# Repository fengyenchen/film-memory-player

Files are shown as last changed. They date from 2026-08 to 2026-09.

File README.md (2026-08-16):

# Film Memory Player

以旋轉底片為互動概念的數位照片播放器。本儲存庫收錄兩種 ESP32 開發板版本；兩者共用同一份正式韌體，程式會依編譯目標自動套用對應的 GPIO。

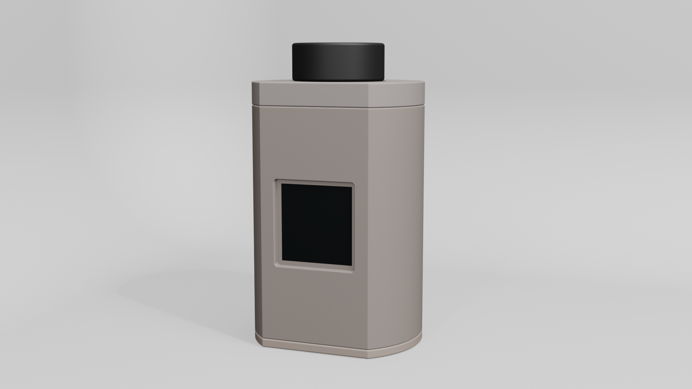
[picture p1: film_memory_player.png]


## 硬體版本

| 版本 | 開發板 | 專案文件 |
| --- | --- | --- |
| XIAO ESP32-C3 | Seeed Studio XIAO ESP32-C3 | [進入專案](xiao-esp32c3/README.md) |
| ESP32-S3 Super Mini | 具 B+ / B- 電池焊盤的 ESP32-S3 Super Mini | [進入專案](esp32-s3-super-mini/README.md) |

正式程式位於 [`firmware/FilmMemoryPlayer/`](firmware/FilmMemoryPlayer/)，只需在 Arduino IDE 選擇正確開發板。各版本資料夾保留接線說明、材料清單與元件測試程式。外殼的 STL 檔可到 [`3d-print-parts/`](3d-print-parts/) 取得。

## 資料夾導覽

```text
.
├─ 3d-print-parts/          外殼的 3D 列印零件
├─ firmware/
│  └─ FilmMemoryPlayer/     S3 與 C3 共用的正式韌體
├─ xiao-esp32c3/            XIAO ESP32-C3 接線、測試與說明
└─ esp32-s3-super-mini/     ESP32-S3 Super Mini 接線、測試與說明
```

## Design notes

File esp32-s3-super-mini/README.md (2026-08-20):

# Film Memory Player

Film Memory Player 是一個以「旋轉底片」為互動概念的數位照片播放器。使用 ESP32-S3 Super Mini、128×128 SPI TFT 與 EC11 旋轉編碼器，完成一台能播放照片、切換自動播放並透過 Wi-Fi 管理相冊的小型裝置。USB-C 可同時供電、燒錄並透過板載充電電路替 LiPo 充電。

## 完成後可以做什麼

- 左右旋轉 EC11 切換上一張或下一張照片。
- 短按旋鈕開啟或停止自動播放。
- 長按約 1.2 秒開啟主選單或返回主選單。
- 主選單可選擇相片、時鐘、表情、Wi-Fi 管理與設定。
- 從手機或電腦一次選擇多張照片上傳。
- 網頁會將照片裁切並縮放成 128×128 JPEG。
- 相片列表提供縮圖、日期時間檔名與單張刪除。
- 可在設定頁調整 `25%`、`50%`、`75%` 或 `100%` 螢幕亮度。
- `SETTINGS` 顯示由 GPIO11 分壓量測的約略電量與電池電壓。
- 長按約 3.5 秒關閉背光並進入休眠；再按一下即可重新啟動。
- 最多儲存 50 張照片。

## 主要材料

- ESP32-S3 Super Mini（具 B+ / B- 電池焊盤版本）
- 128×128 SPI TFT 顯示器
- EC11 旋轉編碼器（含按壓功能）
- 具保護板的單節 3.7V LiPo
- USB-C 傳輸線
- 杜邦線或焊接線材
- 3D 列印外殼

完整品項請看 [材料清單](docs/BOM.md)，接線方式請看 [接線指南](docs/WIRING.md)。

## 資料夾導覽

```text
film_memory_player/
├─ firmware/FilmMemoryPlayer/        S3 與 C3 共用的正式韌體
└─ esp32-s3-super-mini/
   ├─ docs/
   │  ├─ BOM.md                      材料清單
   │  └─ WIRING.md                   接線指南
   ├─ firmware/
   │  ├─ test_button/                EC11 按壓測試
   │  ├─ test_screen/                TFT 紅色畫面測試
   │  └─ test_wifi/                  Wi-Fi 熱點測試
```

外殼的 STL 檔可到專案最外層的 [`3d-print-parts/`](../3d-print-parts/) 取得。

## 建議流程

### 1. 安裝 Arduino IDE 與開發板

在 Arduino IDE 中安裝 ESP32 開發板支援，並選擇：

- 開發板：`ESP32S3 Dev Module`
- USB CDC On Boot：`Enabled`
- USB Mode：`Hardware CDC and JTAG`
- Flash Size：`4MB`
- Partition Scheme：`Custom`
- Serial Monitor：`115200 baud`

### 2. 安裝正式韌體需要的函式庫

從 Arduino IDE Library Manager 安裝：

- `Adafruit GFX Library`
- `Adafruit ST7735 and ST7789 Library`
- `TJpg_Decoder`

`LittleFS`、`WiFi` 與 `WebServer` 由 ESP32 開發板套件提供。

### 3. 依序測試元件

建議先完成單項測試，再燒錄正式韌體：

1. [按鈕測試](firmware/test_button/README.md)：確認 GPIO8 能讀到按下與放開。
2. [螢幕測試](firmware/test_screen/README.md)：確認 128×128 顯示區域能完整顯示紅色。
3. [Wi-Fi 測試](firmware/test_wifi/README.md)：確認手機能找到並連上測試熱點。

每個測試資料夾都有獨立的 `.ino` 與操作說明。測試程式會取代板上原本的程式，完成測試後再上傳正式韌體即可。

### 4. 燒錄正式韌體

1. 開啟專案最外層的 [`firmware/FilmMemoryPlayer/FilmMemoryPlayer.ino`](../firmware/FilmMemoryPlayer/FilmMemoryPlayer.ino)。
2. 確認同一個資料夾內保留 `partitions.csv`。
3. 編譯並上傳。
4. 上傳完成後按一下開發板的 RESET。

如果 Arduino IDE 無法連線：

1. 按住開發板的 BOOT。
2. 按一下 RESET。
3. 放開 BOOT。
4. 再次執行上傳。

## 接線摘要

| 功能 | ESP32-S3 Super Mini GPIO |
| --- | ---: |
| TFT 背光 BL | 1 |
| TFT RST | 2 |
| TFT DC | 4 |
| TFT CS | 5 |
| EC11 CLK | 6 |
| EC11 DT | 7 |
| TFT SCL | 9 |
| TFT SDA | 10 |
| EC11 SW | 8 |
| 電池電壓 ADC | 11（經兩顆 100kΩ 電阻分壓） |

TFT VCC 接 `3V3`，TFT 與 EC11 的 GND 都接到開發板 GND。詳細接法以 [WIRING.md](docs/WIRING.md) 為準。

## 操作方式

| 操作 | 功能 |
| --- | --- |
| 向右旋轉 | 下一張照片 |
| 向左旋轉 | 上一張照片 |
| 短按 | 開啟／停止自動播放 |
| 長按約 1.2 秒後放開 | 開啟主選單／返回主選單 |
| 持續按住約 3.5 秒 | 關閉背光並進入休眠 |
| 休眠後按一下 | 重新啟動 |

## 上傳與管理照片

1. 長按旋鈕約 1.2 秒開啟主選單。
2. 旋轉至 `WI-FI`，短按進入；看到螢幕顯示 `WIFI READY`。
3. 手機或電腦連接 Wi-Fi：
   - 預設名稱：`FilmMemory-Setup`
   - 預設密碼：`film2026`
4. 瀏覽器開啟 `http://192.168.4.1`。
5. 選擇照片並按下「裁切並上傳」。
6. 在下方列表查看縮圖，或刪除指定照片。
7. 在 Wi-Fi 模式短按旋鈕即可關閉 Wi-Fi 並回到主選單。

## 模式說明

- `PHOTO`：旋轉切換照片，短按開啟或暫停幻燈片。
- `CLOCK`：顯示日期與時間；進入 Wi-Fi 管理網頁時會從手機或電腦同步時間，完全斷電後需再次同步。
- `WI-FI`：啟動照片管理熱點與網頁。
- `SETTINGS`：旋轉調整幻燈片間隔、自動休眠時間或螢幕亮度，短按切換設定項目；底部顯示約略電量與電壓。

手機顯示「此網路沒有網際網路」是正常的，請保持連線並直接開啟管理網址。

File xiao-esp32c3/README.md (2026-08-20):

# Film Memory Player

Film Memory Player 是一個以「旋轉底片」為互動概念的數位照片播放器。使用 Seeed Studio XIAO ESP32-C3、128×128 SPI TFT 與 EC11 旋轉編碼器，完成一台能播放照片、切換自動播放並透過 Wi-Fi 管理相冊的小型裝置。USB-C 可同時供電、燒錄與替板載 LiPo 充電

## 完成後可以做什麼

- 左右旋轉 EC11 切換上一張或下一張照片。
- 短按旋鈕開啟或停止自動播放。
- 長按約 1.2 秒開啟主選單或返回主選單。
- 主選單可選擇相片、時鐘、表情、Wi-Fi 管理與設定。
- 從手機或電腦一次選擇多張照片上傳。
- 網頁會將照片裁切並縮放成 128×128 JPEG。
- 相片列表提供縮圖、日期時間檔名與單張刪除。
- 可在設定頁調整 `25%`、`50%`、`75%` 或 `100%` 螢幕亮度。
- 可在設定頁查看由 D1/A1（GPIO3）量測的約略電量與電壓。
- 長按約 3.5 秒關閉背光並進入休眠；再按一下即可重新啟動。
- 最多儲存 50 張照片。

## 主要材料

- Seeed Studio XIAO ESP32-C3
- 128×128 SPI TFT 顯示器
- EC11 旋轉編碼器（含按壓功能）
- 具保護板的單節 3.7V LiPo
- 100kΩ、1% 電阻兩顆（電池電壓分壓）
- USB-C 傳輸線
- 杜邦線或焊接線材
- 3D 列印外殼

完整品項請看 [材料清單](docs/BOM.md)，接線方式請看 [接線指南](docs/WIRING.md)。

## 資料夾導覽

```text
film_memory_player/
├─ firmware/FilmMemoryPlayer/        S3 與 C3 共用的正式韌體
└─ xiao-esp32c3/
   ├─ docs/
   │  ├─ BOM.md                      材料清單
   │  └─ WIRING.md                   接線指南
   ├─ firmware/
   │  ├─ test_button/                EC11 按壓測試
   │  ├─ test_screen/                TFT 紅色畫面測試
   │  └─ test_wifi/                  Wi-Fi 熱點測試
```

外殼的 STL 檔可到專案最外層的 [`3d-print-parts/`](../3d-print-parts/) 取得。

## 建議流程

### 1. 安裝 Arduino IDE 與開發板

在 Arduino IDE 中安裝 ESP32 開發板支援，並選擇：

- 開發板：`ESP32C3 Dev Module`
- USB CDC On Boot：`Enabled`
- Flash Size：`4MB`
- Partition Scheme：`Custom`
- Serial Monitor：`115200 baud`

### 2. 安裝正式韌體需要的函式庫

從 Arduino IDE Library Manager 安裝：

- `Adafruit GFX Library`
- `Adafruit ST7735 and ST7789 Library`
- `TJpg_Decoder`

`LittleFS`、`WiFi` 與 `WebServer` 由 ESP32 開發板套件提供。

### 3. 依序測試元件

建議先完成單項測試，再燒錄正式韌體：

1. [按鈕測試](firmware/test_button/README.md)：確認 GPIO21 能讀到按下與放開。
2. [螢幕測試](firmware/test_screen/README.md)：確認 128×128 顯示區域能完整顯示紅色。
3. [Wi-Fi 測試](firmware/test_wifi/README.md)：確認手機能找到並連上測試熱點。

每個測試資料夾都有獨立的 `.ino` 與操作說明。測試程式會取代板上原本的程式，完成測試後再上傳正式韌體即可。

### 4. 燒錄正式韌體

1. 開啟專案最外層的 [`firmware/FilmMemoryPlayer/FilmMemoryPlayer.ino`](../firmware/FilmMemoryPlayer/FilmMemoryPlayer.ino)。
2. 確認同一個資料夾內保留 `partitions.csv`。
3. 編譯並上傳。
4. 上傳完成後按一下 XIAO Reset。

如果 Arduino IDE 無法連線：

1. 按住 XIAO 的 BOOT。
2. 按一下 RESET。
3. 放開 BOOT。
4. 再次執行上傳。

## 接線摘要

| 功能 | XIAO GPIO |
| --- | ---: |
| TFT 背光 BL | 2 |
| TFT RST | 20（D7） |
| TFT DC | 4 |
| TFT CS | 5 |
| EC11 CLK | 6 |
| EC11 DT | 7 |
| TFT SCL | 8 |
| TFT SDA | 10 |
| EC11 SW | 21 |
| 電池 ADC | 3（D1 / A1，須經兩顆 100kΩ 分壓） |

TFT VCC 接 `3V3`，TFT、EC11 與電池分壓電路的 GND 都接到 XIAO GND。不可將 BAT+ 直接接 GPIO3；詳細接法以 [WIRING.md](docs/WIRING.md) 為準。

## 操作方式

| 操作 | 功能 |
| --- | --- |
| 向右旋轉 | 下一張照片 |
| 向左旋轉 | 上一張照片 |
| 短按 | 開啟／停止自動播放 |
| 長按約 1.2 秒後放開 | 開啟主選單／返回主選單 |
| 持續按住約 3.5 秒 | 關閉背光並進入休眠 |
| 休眠後按一下 | 重新啟動 |

## 上傳與管理照片

1. 長按旋鈕約 1.2 秒後放開，進入主選單。
2. 旋轉到 `WI-FI`，短按進入並等待畫面顯示 `WIFI READY`。
3. 手機或電腦連接 Wi-Fi：
   - 預設名稱：`FilmMemory-Setup`
   - 預設密碼：`film2026`
4. 瀏覽器開啟 `http://192.168.4.1`。
5. 選擇照片並按下「裁切並上傳」。
6. 在下方列表查看縮圖，或刪除指定照片。
7. 在 Wi-Fi 模式短按旋鈕即可關閉 Wi-Fi 並回到主選單。

手機顯示「此網路沒有網際網路」是正常的，請保持連線並直接開啟管理網址。

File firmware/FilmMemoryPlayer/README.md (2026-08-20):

# Film Memory Player 共用韌體

這是共用的正式韌體。程式會依 Arduino IDE 選擇的編譯目標，自動在 `Config.h` 套用對應 GPIO。使用 128×128 SPI TFT、EC11 旋轉編碼器與板載 LittleFS，提供照片播放、時鐘、表情、Wi-Fi 相簿管理、設定與休眠功能。

## 功能

- 從 LittleFS 播放最多 50 張照片。
- 手動切換照片或啟用自動播放。
- 顯示日期、星期與時間。
- 旋轉選擇 10 種黑底白線表情。
- 透過手機瀏覽器上傳、預覽、刪除或清空照片。
- 調整幻燈片間隔、自動休眠時間與螢幕亮度。
- 可在設定頁顯示約略電量與電壓；S3 使用 GPIO11，XIAO C3 使用 D1/A1（GPIO3），兩者都需外接兩顆 100kΩ 分壓電阻。
- 長按旋鈕進入低功耗休眠，再按一下喚醒。
- 自動保存設定與最後選擇的表情。

## Arduino IDE 準備

### 1. 安裝開發板套件

在 Arduino IDE 的 Boards Manager 安裝 Espressif 的 `esp32` 套件，再依開發板設定：

| 選項 | ESP32-S3 Super Mini | XIAO ESP32-C3 |
| --- | --- | --- |
| Board | `ESP32S3 Dev Module` | `ESP32C3 Dev Module` |
| USB CDC On Boot | `Enabled` | `Enabled` |
| Partition Scheme | `Custom` | `Custom` |
| Serial Monitor | `115200 baud` | `115200 baud` |

### 2. 安裝函式庫

從 Library Manager 安裝：

- `Adafruit GFX Library`
- `Adafruit ST7735 and ST7789 Library`
- `TJpg_Decoder`

`LittleFS`、`WiFi`、`WebServer`、`Preferences` 與 `SPI` 由 ESP32 開發板套件提供。

## 編譯與燒錄

1. 保持這個資料夾名稱為 `FilmMemoryPlayer`。
2. 確認所有 `.cpp`、`.h`、`.ino` 與 `partitions.csv` 都在同一個資料夾。
3. 使用 Arduino IDE 開啟 [FilmMemoryPlayer.ino](FilmMemoryPlayer.ino)。
4. 依實際硬體選擇開發版，程式會自動套用對應接腳。
5. 選擇正確的 USB 連接埠。
6. 按下 Verify 確認可以編譯。
7. 按下 Upload 燒錄。
8. 上傳完成後按一下開發板的 RESET。

若無法進入燒錄模式：

1. 按住開發板的 BOOT。
2. 按一下 RESET。
3. 放開 BOOT。
4. 再次執行 Upload。

`partitions.csv` 會建立約 1.94 MiB 的照片儲存空間。請勿刪除或改名；更換 Partition Scheme、格式化或重新分割 Flash 可能清除已上傳的照片。

## 首次使用

1. 開機後裝置進入 `PHOTO` 模式。
2. 如果尚未上傳照片，畫面會顯示 `NO PHOTOS`。
3. 長按旋鈕約 1.2 秒後放開，進入主選單。
4. 旋轉到 `WI-FI`，短按進入。
5. 用手機連接：
   - Wi-Fi：`FilmMemory-Setup`
   - 密碼：`film2026`
6. 瀏覽器開啟 [http://192.168.4.1](http://192.168.4.1)。
7. 選取照片、裁切並上傳。
8. 在 Wi-Fi 模式短按旋鈕，關閉熱點並回到主選單。
9. 進入 `PHOTO` 開始播放。

網頁會將圖片裁切並縮放為 128×128 JPEG。管理頁開啟時也會用手機／電腦時間同步裝置時鐘。

## 操作方式

### 共通操作

| 操作 | 功能 |
| --- | --- |
| 長按約 1.2 秒後放開 | 從目前模式進入主選單 |
| 在主選單旋轉 | 選擇模式 |
| 在主選單短按 | 進入選取的模式 |
| 持續按住約 3.5 秒 | 關閉背光並進入休眠 |
| 休眠時按一下並放開 | 喚醒並重新啟動 |

### 模式

| 模式 | 旋轉 | 短按 | 說明 |
| --- | --- | --- | --- |
| `PHOTO` | 上一張／下一張 | 開啟或停止幻燈片 | 播放 LittleFS 相簿 |
| `CLOCK` | 無 | 無 | 顯示時間、日期與星期 |
| `EMOTES` | 切換表情 | 無 | 顯示 10 種靜態線條表情 |
| `WI-FI` | 無 | 關閉 Wi-Fi 並回主選單 | 啟動照片管理頁 |
| `SETTINGS` | 修改目前選項 | 切換下一個選項 | 設定幻燈片、自動休眠與亮度，並顯示約略電量 |

幻燈片可選 `2`、`3.5`、`5`、`10` 秒；自動休眠可選 `OFF`、`1`、`3`、`5` 分鐘；螢幕亮度可選 `25%`、`50%`、`75%`、`100%`。設定會自動保存，重新開機後仍會套用。

如果剛旋轉完照片，程式會短暫忽略按鍵，以免轉動旋鈕時誤觸自動播放。

## Wi-Fi 相簿管理

管理頁提供：

- 多張照片依序裁切與上傳。
- 顯示剩餘儲存空間。
- 照片縮圖與檔案資訊。
- 單張刪除或清空全部照片。
- 裝置時間同步。

Wi-Fi 模式是本機 SoftAP，不需要網際網路。手機若提示「此網路無網際網路」，仍可保持連線並開啟 `192.168.4.1`。

## 資料夾結構

```text
FilmMemoryPlayer/
├─ FilmMemoryPlayer.ino   # setup()、loop() 與初始化流程
├─ Config.h               # 自動選擇 S3/C3 GPIO，以及共用尺寸與常數
├─ BatteryMonitor.h/.cpp  # S3/C3 電池電壓與百分比估算
├─ AppState.h/.cpp        # 共用狀態、TFT、WebServer、Preferences
├─ DisplayUtils.h/.cpp    # 背光、置中文字與訊息畫面
├─ PhotoMode.h/.cpp       # JPEG、照片掃描、顯示與切換
├─ ClockMode.h/.cpp       # 時鐘畫面
├─ EmoteMode.h/.cpp       # 線條表情繪製
├─ MenuMode.h/.cpp        # 主選單與模式切換
├─ SettingsMode.h/.cpp    # 設定畫面與保存
├─ WifiManager.h/.cpp     # Wi-Fi、上傳、刪除與時間同步
├─ WebPage.h/.cpp         # 內嵌管理網頁
├─ Encoder.h/.cpp         # EC11 旋轉、短按與長按
├─ PowerManager.h/.cpp    # 休眠與按鍵喚醒
├─ partitions.csv         # 4 MB Flash 自訂分割表
└─ README.md
```

Arduino IDE 會自動編譯同一個 sketch 資料夾內的所有 `.cpp` 檔。請勿只複製 `.ino`，否則會出現缺少標頭或未定義函式的錯誤。

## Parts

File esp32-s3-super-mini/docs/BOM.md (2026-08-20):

# 材料清單

| 分類 | 品項 | 規格 | 數量 | 備註 |
|---|---|---|---:|---|
| 電子 | 主控制器 | ESP32-S3 Super Mini（具 B+ / B- 焊盤版本） | 1 | 使用原生 USB-C 與板載 LiPo 充電電路 |
| 電子 | 顯示器 | 1.44 吋 128×128 ST7735S SPI TFT | 1 |  |
| 電子 | 旋轉編碼器 | EC11，6 mm D 軸、含按壓 | 1 |  | https://shopee.tw/EC11-360%E5%BA%A6%E9%80%A3%E7%BA%8C%E6%97%8B%E8%BD%89-%E7%B7%A8%E7%A2%BC%E5%99%A8%E6%A8%A1%E7%B5%84-%E6%95%B8%E4%BD%8D%E8%A8%8A%E8%99%9F-D%E5%AD%97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 |
| 電源 | 鋰電池 | 具保護板 503040 單節 3.7V LiPo | 1 | 正極接 B+、負極接 B-；不可接反 |
| 電子 | 分壓電阻 | 100kΩ、1%、1/4W 或更小 | 2 | 電池電量偵測，接到 GPIO11 |

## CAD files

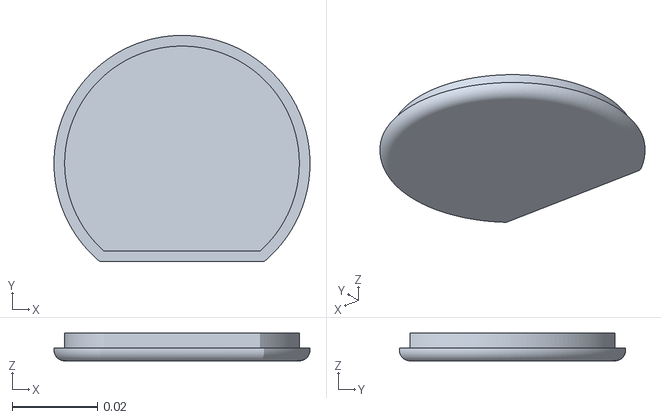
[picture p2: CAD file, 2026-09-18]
3d-print-parts/1.stl
0.06 x 0.053 x 0.0065

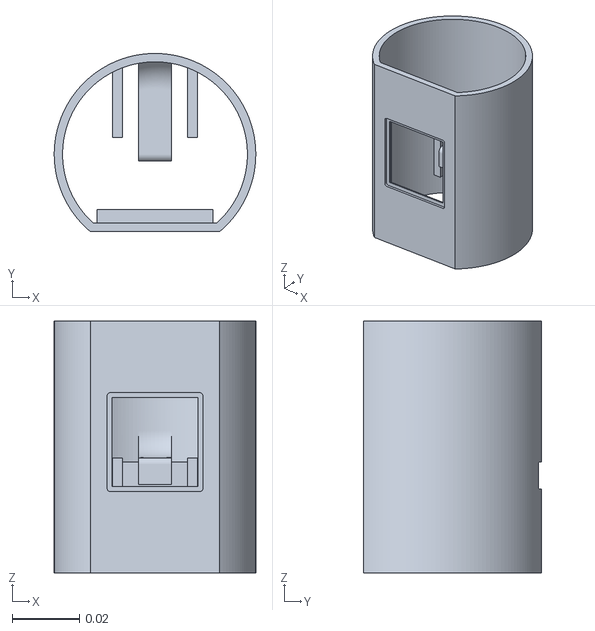
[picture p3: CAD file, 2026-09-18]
3d-print-parts/2.stl
0.06 x 0.053 x 0.075

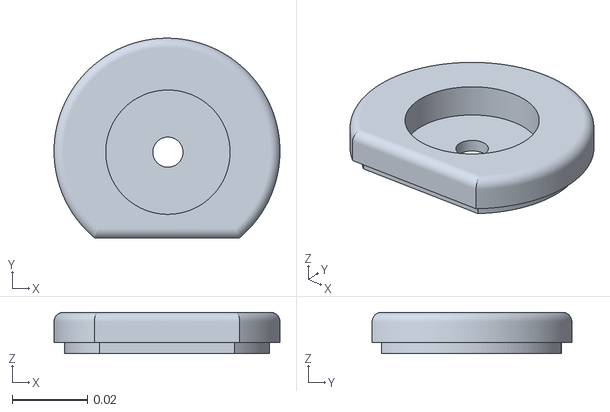
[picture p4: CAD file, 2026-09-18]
3d-print-parts/3.stl
0.06 x 0.053 x 0.011

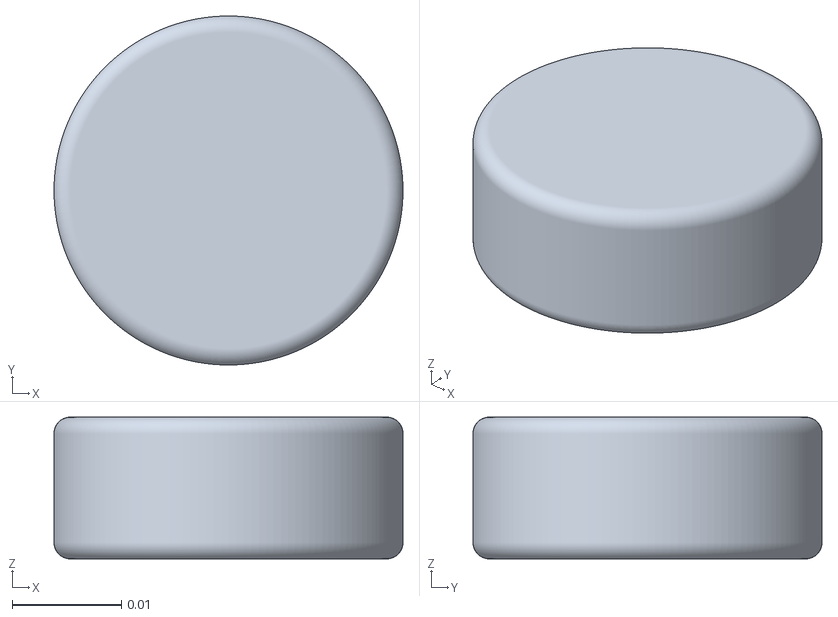
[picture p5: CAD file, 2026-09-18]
3d-print-parts/4.stl
0.032 x 0.032 x 0.013

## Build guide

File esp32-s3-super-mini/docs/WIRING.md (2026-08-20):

# 接線指南

## 主要控制板：ESP32-S3 Super Mini

本文件對應具有 `B+`、`B-` 電池焊盤的 ESP32-S3 Super Mini。所有模組必須共地：TFT、EC11 與分壓電路的 GND 都接到開發板 `GND`；TFT 與 EC11 使用開發板的 `3V3` 供電。

> **Wi-Fi 天線注意事項：**
> - 這塊板使用板載 PCB 天線，不需要另外安裝天線。
> - 天線端不要緊貼 LiPo、TFT 金屬背板或大量導線，也不要用金屬件包覆。

---

## 電池與充電

```text
LiPo 正極 → ESP32-S3 Super Mini 的 B+
LiPo 負極 → ESP32-S3 Super Mini 的 B-

USB-C 充電器 → ESP32-S3 Super Mini 原生 USB-C
```

USB-C 線直接插入開發板，另一端接一般 5V USB 充電器。只使用單節標稱 3.7V、充滿 4.2V 且具有保護板的 LiPo。

依此版本接腳圖標註，板載充電電路的預設充電電流約為 100mA。不同賣家的板子可能使用不同充電晶片，實際規格仍以商品頁為準。

> **電池安全：**
> - `B+`、`B-` 不可接反，也不可將 5V 接到 `B+`。
> - 不要同時使用外接 TP4056 與板載充電電路替同一顆電池充電。
> - 焊接前先拔除 USB-C，避免正負極或裸露接點短路。

---

## 電量偵測

使用兩顆 `100kΩ、1%` 電阻做 1:2 分壓。兩顆電阻的中間接點連到 GPIO11：

```text
B+ ── R1（100kΩ）──●── R2（100kΩ）── B-
                    │
                 GPIO11
```

- `B+` 焊盤同時焊接電池紅線與 R1 的一端。
- `B-` 焊盤同時焊接電池黑線與 R2 的一端。
- R1、R2 剩下的兩端焊在一起，形成中間接點，再從這裡接到 GPIO11。
- `B-` 與開發板 GND 共地；如果 B- 焊盤太擠，R2 下端也可以改接開發板的 GND 腳。

單節 LiPo 充滿時最高約 4.2V，經分壓後 GPIO11 約讀到 2.1V。不可將 `B+` 直接接到 GPIO11。`SETTINGS` 顯示的是依電壓估算的約略百分比；USB 充電或負載變化時，讀值可能浮動或偏高。

---

## 螢幕模組（ST7735S 128×128 SPI TFT）

這塊螢幕使用 SPI 通訊，背光由 ESP32-S3 Super Mini 的 GPIO1 直接控制。

| TFT 螢幕腳位標示 | 開發板腳位標示 | GPIO 編號 | 說明 |
| --- | --- | ---: | --- |
| **VCC / VDD** | `3V3` | - | 螢幕電源（3.3V） |
| **GND** | `GND` | - | 接地 |
| **SCL / SCK** | `GPIO9` | 9 | SPI 時脈線（Clock） |
| **SDA / MOSI** | `GPIO10` | 10 | SPI 資料線（Data） |
| **RES / RST** | `GPIO2` | 2 | 螢幕重置（Reset） |
| **DC / RS** | `GPIO4` | 4 | 資料／指令切換（Data/Command） |
| **CS / CE** | `GPIO5` | 5 | 晶片選擇（Chip Select） |
| **BLK / BL** | `GPIO1` | 1 | 螢幕背光直接控制 |

---

## 背光控制

```text
ESP32-S3 Super Mini GPIO1 → TFT BLK / BL
```

> **背光注意事項：**
> GPIO1 為 HIGH 時背光開啟，LOW 時背光關閉。進入休眠模式時，程式會將 GPIO1 鎖定為 LOW。

---

## 旋轉編碼器模組（EC11）

EC11 旋轉編碼器通常有 5 支腳：一側 3 支為旋轉訊號，另一側 2 支為按鈕訊號。

| EC11 腳位標示 | 開發板腳位標示 | GPIO 編號 | 說明 |
| --- | --- | ---: | --- |
| **GND / 共用端 C** | `GND` | - | 旋轉訊號的共用接地 |
| **+ / VCC** | `3V3` | - | 供電 |
| **CLK / A 相** | `GPIO6` | 6 | 旋轉觸發訊號 A |
| **DT / B 相** | `GPIO7` | 7 | 旋轉觸發訊號 B |
| **SW / 按壓開關** | `GPIO8` | 8 | 按鍵輸入與休眠喚醒訊號 |

> **編碼器注意事項：**
> 1. GPIO6、GPIO7、GPIO8 直接依照上表接線。
> 2. 如果向右轉卻變成上一張照片，將 CLK（GPIO6）與 DT（GPIO7）兩條線互換。

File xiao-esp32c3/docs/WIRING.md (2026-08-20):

# 接線指南

## 主要控制板：Seeed Studio XIAO ESP32-C3

本文件對應 Seeed Studio XIAO ESP32-C3。所有模組必須共地：TFT、EC11 與分壓電路的 GND 都接到開發板 `GND`；TFT 與 EC11 使用開發板的 `3V3` 供電。

> **Wi-Fi 天線注意事項：**
> - 確認 IPEX 天線接頭已確實垂直扣緊於 XIAO 的金色底座。
> - 天線貼片不要緊貼 LiPo、TFT 金屬背板或大量導線，也不要用金屬件包覆。
> - 天線盡量固定在遠離金屬與電源線的非金屬外殼內側。

---

## 電池與充電

```text
LiPo 正極 → XIAO 背面的 BAT+
LiPo 負極 → XIAO 背面的 BAT-

USB-C 充電器 → XIAO 原生 USB-C
```

USB-C 線直接插入開發板，另一端接一般 5V USB 充電器。只使用單節標稱 3.7V、充滿 4.2V 且具有保護板的 LiPo。

XIAO ESP32-C3 的官方充電電流約為 380mA，電池必須允許此充電電流。

> **電池安全：**
> - `BAT+`、`BAT-` 不可接反，也不可將 5V 接到 `BAT+`。
> - 不要同時使用外接 TP4056 與板載充電電路替同一顆電池充電。
> - 焊接前先拔除 USB-C，避免正負極或裸露接點短路。

---

## 電量偵測

使用兩顆 `100kΩ、1%` 電阻做 1:2 分壓。兩顆電阻的中間接點連到 D1 / A1（GPIO3）：

```text
BAT+ ── R1（100kΩ）──●── R2（100kΩ）── BAT-
                     │
               D1 / A1 / GPIO3
```

- `BAT+` 焊盤同時焊接電池紅線與 R1 的一端。
- `BAT-` 焊盤同時焊接電池黑線與 R2 的一端。
- R1、R2 剩下的兩端焊在一起，形成中間接點，再從這裡接到 D1 / A1（GPIO3）。
- `BAT-` 與開發板 GND 共地；如果 BAT- 焊盤太擠，R2 下端也可以改接開發板的 GND 腳。

單節 LiPo 充滿時最高約 4.2V，經分壓後 GPIO3 約讀到 2.1V。不可將 `BAT+` 直接接到 GPIO3。`SETTINGS` 顯示的是依電壓估算的約略百分比；USB 充電或負載變化時，讀值可能浮動或偏高。

---

## 螢幕模組（ST7735S 128×128 SPI TFT）

這塊螢幕使用 SPI 通訊，背光由 XIAO ESP32-C3 的 D0（GPIO2）直接控制。

| TFT 螢幕腳位標示 | 開發板腳位標示 | GPIO 編號 | 說明 |
| --- | --- | ---: | --- |
| **VCC / VDD** | `3V3` | - | 螢幕電源（3.3V） |
| **GND** | `GND` | - | 接地 |
| **SCL / SCK** | `D8` | 8 | SPI 時脈線（Clock） |
| **SDA / MOSI** | `D10` | 10 | SPI 資料線（Data） |
| **RES / RST** | `D7` | 20 | 螢幕重置（Reset） |
| **DC / RS** | `D2` | 4 | 資料／指令切換（Data/Command） |
| **CS / CE** | `D3` | 5 | 晶片選擇（Chip Select） |
| **BLK / BL** | `D0` | 2 | 螢幕背光直接控制 |

---

## 背光控制

```text
XIAO D0（GPIO2）→ TFT BLK / BL
```

> **背光注意事項：**
> D0（GPIO2）為 HIGH 時背光開啟，LOW 時背光關閉。進入休眠模式時，程式會將 GPIO2 鎖定為 LOW。

---

## 旋轉編碼器模組（EC11）

EC11 旋轉編碼器通常有 5 支腳：一側 3 支為旋轉訊號，另一側 2 支為按鈕訊號。

| EC11 腳位標示 | 開發板腳位標示 | GPIO 編號 | 說明 |
| --- | --- | ---: | --- |
| **GND / 共用端 C** | `GND` | - | 旋轉訊號的共用接地 |
| **+ / VCC** | `3V3` | - | 供電 |
| **CLK / A 相** | `D4` | 6 | 旋轉觸發訊號 A |
| **DT / B 相** | `D5` | 7 | 旋轉觸發訊號 B |
| **SW / 按壓開關** | `D6` | 21 | 按鍵輸入與休眠喚醒訊號 |

> **編碼器注意事項：**
> 1. D4、D5、D6 直接依照上表接線。
> 2. 如果向右轉卻變成上一張照片，將 CLK（D4）與 DT（D5）兩條線互換。

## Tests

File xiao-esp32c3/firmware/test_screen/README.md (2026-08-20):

# TFT 螢幕測試

這個測試會直接向 128×128 TFT 寫入純紅色畫面，用來確認螢幕供電、SPI 接線、重設腳位與顯示範圍是否正常。

## 接線

| TFT 腳位 | XIAO ESP32-C3 |
| --- | --- |
| VCC / VDD | 3V3 |
| GND | GND |
| BLK / BL | GPIO2 |
| RES / RST | GPIO20（D7） |
| DC / RS | GPIO4 |
| CS / CE | GPIO5 |
| SCL / SCK | GPIO8 |
| SDA / MOSI | GPIO10 |

## Arduino IDE 設定

- 開發板：`XIAO_ESP32C3`
- USB CDC On Boot：`Enabled`
- 上傳檔案：`test_screen.ino`
- 這個測試直接傳送顯示指令，不需要額外顯示函式庫。

## 測試步驟

1. 先拔除 USB-C，再依照接線表連接 TFT。
2. 再接上 USB-C，開啟並上傳 `test_screen.ino`。
3. 等待約 1 秒觀察螢幕。

## 成功判定

整個 128×128 顯示區域呈現均勻紅色，沒有白邊、位移、雜色或破碎區塊，即代表主要螢幕接線正常。

## 背光測試方式

程式會在初始化期間先關閉 GPIO2 背光，完成純紅色畫面寫入後再開啟，因此啟動時短暫黑屏是正常現象。

## 常見問題

- 完全不亮：先確認 GPIO2 背光控制與 3V3、GND。
- 全白：優先檢查 GPIO20、GPIO4、GPIO5、GPIO8、GPIO10。
- 有畫面但位置偏移：確認使用的是本專案測試過的 128×128 面板。
- 顏色不是紅色：可能是面板色彩順序不同，可再確認初始化設定。

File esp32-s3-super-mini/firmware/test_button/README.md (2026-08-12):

# 按鈕測試

這個測試用來確認 EC11 旋鈕的按壓開關是否能被 ESP32-S3 Super Mini 正確讀取。

## 接線

| EC11 按鈕腳位 | ESP32-S3 Super Mini |
| --- | --- |
| SW | GPIO8 |
| 按鈕另一腳 | GND |

## Arduino IDE 設定

- 開發板：`ESP32S3 Dev Module`
- USB CDC On Boot：`Enabled`
- Partition Scheme：`Custom`
- Serial Monitor：`115200 baud`
- 上傳檔案：`test_button.ino`

## 測試步驟

1. 完成接線後，以 USB-C 將 ESP32-S3 Super Mini 連接電腦。
2. 開啟 `test_button.ino` 並上傳。
3. 開啟 Arduino IDE 的 Serial Monitor。
4. 不按旋鈕時，應持續看到 `未按下 (HIGH)`。
5. 按住旋鈕時，應看到 LOW 訊息。
6. 放開旋鈕後，應恢復顯示 HIGH。

## 成功判定

按下與放開時，Serial Monitor 能在 LOW 與 HIGH 之間切換，表示按壓開關、GPIO8 與 GND 接線正常。

## 常見問題

- 一直顯示 HIGH：檢查 SW 是否接到 GPIO8，以及按鈕另一腳是否接到 GND。
- 一直顯示 LOW：檢查 SW 線與 GND 是否短接，或旋鈕是否卡在按下狀態。
- Serial Monitor 沒有文字：確認傳輸速率為 115200、USB CDC On Boot 已啟用，並按一下 RESET。

> 這個程式只測試旋鈕按壓，不測試左右旋轉。

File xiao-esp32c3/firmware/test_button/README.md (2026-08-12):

# 按鈕測試

這個測試用來確認 EC11 旋鈕的按壓開關是否能被 XIAO ESP32-C3 正確讀取。

## 接線

| EC11 按鈕腳位 | XIAO ESP32-C3 |
| --- | --- |
| SW | GPIO21 |
| 按鈕另一腳 | GND |

## Arduino IDE 設定

- 開發板：`XIAO_ESP32C3`
- USB CDC On Boot：`Enabled`
- Partition Scheme：`Custom`
- Serial Monitor：`115200 baud`
- 上傳檔案：`test_button.ino`

## 測試步驟

1. 完成接線後，以 USB-C 將 XIAO 連接電腦。
2. 開啟 `test_button.ino` 並上傳。
3. 開啟 Arduino IDE 的 Serial Monitor。
4. 不按旋鈕時，應持續看到 `未按下 (HIGH)`。
5. 按住旋鈕時，應看到 LOW 訊息。
6. 放開旋鈕後，應恢復顯示 HIGH。

## 成功判定

按下與放開時，Serial Monitor 能在 LOW 與 HIGH 之間切換，表示按壓開關、GPIO21 與 GND 接線正常。

## 常見問題

- 一直顯示 HIGH：檢查 SW 是否接到 GPIO21，以及按鈕另一腳是否接到 GND。
- 一直顯示 LOW：檢查 SW 線與 GND 是否短接，或旋鈕是否卡在按下狀態。
- Serial Monitor 沒有文字：確認傳輸速率為 115200，並按一下 XIAO Reset。

> 這個程式只測試旋鈕按壓，不測試左右旋轉。

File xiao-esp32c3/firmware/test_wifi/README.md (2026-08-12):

# Wi-Fi 熱點測試

這個測試用來確認 XIAO ESP32-C3 能否建立 Wi-Fi SoftAP 熱點，以及手機能否找到並連線。

## 測試前準備

- 將外接 Wi-Fi 天線垂直扣緊在 XIAO 的天線接座。
- 天線不要貼在電池、TFT 金屬背板或大量導線旁邊。
- 這個測試不需要連接 TFT 或 EC11。

## Arduino IDE 設定

- 開發板：`XIAO_ESP32C3`
- USB CDC On Boot：`Enabled`
- Serial Monitor：`115200 baud`
- 上傳檔案：`test_wifi.ino`

## 測試步驟

1. 使用 USB-C 將 XIAO 連接電腦。
2. 上傳 `test_wifi.ino`。
3. 開啟 Serial Monitor。
4. 用手機搜尋 Wi-Fi 網路 `XIAO-Test-AP`。
5. 這是測試用的開放網路，不需要密碼。
6. 連線後，Serial Monitor 應顯示熱點 IP，通常是 `192.168.4.1`。

## 成功判定

- Serial Monitor 顯示 `熱點發射成功`。
- 手機可以找到並連上 `XIAO-Test-AP`。
- 手機提示「沒有網際網路」是正常現象，這個熱點只用於裝置本機通訊。

## 常見問題

- 手機找不到熱點：確認天線接頭已扣緊，然後按一下 XIAO Reset。
- Serial Monitor 沒有文字：確認傳輸速率為 115200。
- 顯示熱點發射失敗：重新插拔 USB-C，再次上傳測試程式。
- 手機自動切回行動網路：暫時關閉手機的自動切換網路功能，再重新連線。

> 正式韌體使用的熱點名稱與密碼和此測試程式不同；這個開放熱點只用於確認 Wi-Fi 硬體功能。

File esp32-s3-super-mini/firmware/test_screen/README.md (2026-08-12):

# TFT 螢幕測試

這個測試會直接向 128×128 TFT 寫入純紅色畫面，用來確認螢幕供電、SPI 接線、重設腳位與顯示範圍是否正常。

## 接線

| TFT 腳位 | ESP32-S3 Super Mini |
| --- | --- |
| VCC / VDD | 3V3 |
| GND | GND |
| BLK / BL | GPIO1 |
| RES / RST | GPIO2 |
| DC / RS | GPIO4 |
| CS / CE | GPIO5 |
| SCL / SCK | GPIO9 |
| SDA / MOSI | GPIO10 |

## Arduino IDE 設定

- 開發板：`ESP32S3 Dev Module`
- USB CDC On Boot：`Enabled`
- 上傳檔案：`test_screen.ino`
- 這個測試直接傳送顯示指令，不需要額外顯示函式庫。

## 測試步驟

1. 先拔除 USB-C，再依照接線表連接 TFT。
2. 再接上 USB-C，開啟並上傳 `test_screen.ino`。
3. 等待約 1 秒觀察螢幕。

## 成功判定

整個 128×128 顯示區域呈現均勻紅色，沒有白邊、位移、雜色或破碎區塊，即代表主要螢幕接線正常。

## 背光測試方式

程式會在初始化期間先關閉 GPIO1 背光，完成純紅色畫面寫入後再開啟，因此啟動時短暫黑屏是正常現象。

## 常見問題

- 完全不亮：先確認 GPIO1 背光控制與 3V3、GND。
- 全白：優先檢查 GPIO2、GPIO4、GPIO5、GPIO9、GPIO10。
- 有畫面但位置偏移：確認使用的是本專案測試過的 128×128 面板。
- 顏色不是紅色：可能是面板色彩順序不同，可再確認初始化設定。

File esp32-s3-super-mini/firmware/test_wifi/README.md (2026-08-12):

# Wi-Fi 熱點測試

這個測試用來確認 ESP32-S3 Super Mini 能否建立 Wi-Fi SoftAP 熱點，以及手機能否找到並連線。

## 測試前準備

- 板載 PCB 天線端不要緊貼電池、TFT 金屬背板或大量導線。
- 這個測試不需要連接 TFT 或 EC11。

## Arduino IDE 設定

- 開發板：`ESP32S3 Dev Module`
- USB CDC On Boot：`Enabled`
- Serial Monitor：`115200 baud`
- 上傳檔案：`test_wifi.ino`

## 測試步驟

1. 使用 USB-C 將 ESP32-S3 Super Mini 連接電腦。
2. 上傳 `test_wifi.ino`。
3. 開啟 Serial Monitor。
4. 用手機搜尋 Wi-Fi 網路 `S3-SuperMini-Test`。
5. 這是測試用的開放網路，不需要密碼。
6. 連線後，Serial Monitor 應顯示熱點 IP，通常是 `192.168.4.1`。

## 成功判定

- Serial Monitor 顯示 `熱點發射成功`。
- 手機可以找到並連上 `S3-SuperMini-Test`。
- 手機提示「沒有網際網路」是正常現象，這個熱點只用於裝置本機通訊。

## 常見問題

- 手機找不到熱點：讓板載天線遠離金屬遮蔽物，然後按一下 RESET。
- Serial Monitor 沒有文字：確認傳輸速率為 115200。
- 顯示熱點發射失敗：重新插拔 USB-C，再次上傳測試程式。
- 手機自動切回行動網路：暫時關閉手機的自動切換網路功能，再重新連線。

> 正式韌體使用的熱點名稱與密碼和此測試程式不同；這個開放熱點只用於確認 Wi-Fi 硬體功能。

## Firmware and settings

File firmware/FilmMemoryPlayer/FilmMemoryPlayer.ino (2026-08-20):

/*
 * Film Memory Player
 *
 * The sketch entry point coordinates initialization and the main loop.
 * Feature implementations live in the adjacent .cpp/.h modules.
 */

#include <Arduino.h>
#include <LittleFS.h>
#include <SPI.h>
#include <TJpg_Decoder.h>
#include <driver/gpio.h>
#include <sys/time.h>
#include <time.h>

#include "AppState.h"
#include "BatteryMonitor.h"
#include "ClockMode.h"
#include "Config.h"
#include "DisplayUtils.h"
#include "Encoder.h"
#include "PhotoMode.h"
#include "PowerManager.h"

void setup() {
  Serial.begin(115200);
  delay(500);

  // 台灣時區；網頁會把手機／電腦的 Unix 時間同步給裝置。
  setenv("TZ", "CST-8", 1);
  tzset();
  preferences.begin("film-memory", false);
  slideIntervalIndex = preferences.getUChar("slide", 1);
  autoSleepIndex = preferences.getUChar("sleep", 0);
  brightnessIndex = preferences.getUChar("bright", BRIGHTNESS_OPTION_COUNT - 1);
  currentExpression = preferences.getUChar("emote", 0);
  if (slideIntervalIndex >= OPTION_COUNT) slideIntervalIndex = 1;
  if (autoSleepIndex >= OPTION_COUNT) autoSleepIndex = 0;
  if (brightnessIndex >= BRIGHTNESS_OPTION_COUNT) {
    brightnessIndex = BRIGHTNESS_OPTION_COUNT - 1;
  }
  if (currentExpression >= EXPRESSION_COUNT) currentExpression = 0;

  // 若前一次休眠鎖住背光腳，開機時先解除，再由程式正常控制。
  gpio_hold_dis(static_cast<gpio_num_t>(PIN_TFT_BL));
  pinMode(PIN_TFT_BL, OUTPUT);
  setBacklight(false); // 初始化完成前先關背光，避免看到白屏／雜訊

  pinMode(PIN_ENCODER_A, INPUT_PULLUP);
  pinMode(PIN_ENCODER_B, INPUT_PULLUP);
  pinMode(PIN_ENCODER_SW, INPUT_PULLUP);
  initBatteryMonitor();

  // 使用目前開發板的硬體 SPI，完整 128x128 畫面約十多毫秒送完。
  SPI.begin(PIN_TFT_SCK, -1, PIN_TFT_MOSI, PIN_TFT_CS);
  tft.init(DISPLAY_W, DISPLAY_H);
  tft.setSPISpeed(TFT_SPI_HZ);
  // 這塊 128x128 ST7735S 的可視記憶體從 (0,0) 開始。
  // 覆寫 Adafruit 預設的置中位移，確保繪圖座標對齊 (0,0) 至 (127,127)。
  tft.use128x128ZeroOffset();
  tft.fillScreen(ST77XX_BLACK);
  tft.invertDisplay(false);
  tft.sendCommand(0x36, (const uint8_t[]){0x08}, 1); // BGR 色彩修正
  setBacklight(true);

  TJpgDec.setJpgScale(1);
  TJpgDec.setSwapBytes(false);
  TJpgDec.setCallback(tftJpegOutput);

  encoderPrevious = (digitalRead(PIN_ENCODER_A) << 1) | digitalRead(PIN_ENCODER_B);
  buttonLastReading = buttonStable = digitalRead(PIN_ENCODER_SW);
  if (buttonStable == LOW) buttonPressedAt = millis();

  fileSystemReady = LittleFS.begin(true);
  if (!fileSystemReady) {
    showMessage("FS ERROR", "Formatting...");
    LittleFS.format();
    LittleFS.begin(true);
  }
  LittleFS.mkdir("/photos");
  scanPhotos();

  appMode = AppMode::PHOTO;
  lastUserActionAt = millis();
  drawPhoto();
}

void loop() {
  pollButton();

  if (setupMode) {
    server.handleClient();
    delay(2);
    return;
  }

  pollEncoder();
  const uint32_t now = millis();

  if (expressionSelectionDirty && now - expressionSelectionChangedAt >= 750) {
    preferences.putUChar("emote", currentExpression);
    expressionSelectionDirty = false;
  }

  if (appMode == AppMode::CLOCK && now - lastClockDrawAt >= 1000) {
    drawClock();
  }

  if (appMode == AppMode::PHOTO && autoplay && photoCount > 1 &&
      now - lastSlideAt >= SLIDE_INTERVALS_MS[slideIntervalIndex]) {
    currentPhoto = (currentPhoto + 1) % photoCount;
    lastSlideAt = now;
    drawPhoto();
  }

  const uint16_t sleepMinutes = AUTO_SLEEP_MINUTES[autoSleepIndex];
  if (sleepMinutes > 0 && now - lastUserActionAt >= uint32_t(sleepMinutes) * 60000UL) {
    enterSleep();
  }
  delay(1);
}

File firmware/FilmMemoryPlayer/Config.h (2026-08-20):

#pragma once

#include <Arduino.h>

#if defined(CONFIG_IDF_TARGET_ESP32S3)

constexpr char BOARD_NAME[] = "ESP32-S3 Super Mini";
constexpr int PIN_TFT_BL = 1;
constexpr int PIN_TFT_RST = 2;
constexpr int PIN_TFT_DC = 4;
constexpr int PIN_TFT_CS = 5;
constexpr int PIN_ENCODER_A = 6;
constexpr int PIN_ENCODER_B = 7;
constexpr int PIN_ENCODER_SW = 8;
constexpr int PIN_TFT_SCK = 9;
constexpr int PIN_TFT_MOSI = 10;
constexpr int PIN_BATTERY_ADC = 11;
constexpr bool HAS_BATTERY_MONITOR = true;

#elif defined(CONFIG_IDF_TARGET_ESP32C3)

constexpr char BOARD_NAME[] = "Seeed Studio XIAO ESP32-C3";
constexpr int PIN_TFT_BL = 2;       // D0
constexpr int PIN_TFT_RST = 20;     // D7
constexpr int PIN_TFT_DC = 4;       // D2
constexpr int PIN_TFT_CS = 5;       // D3
constexpr int PIN_ENCODER_A = 6;    // D4
constexpr int PIN_ENCODER_B = 7;    // D5
constexpr int PIN_ENCODER_SW = 21;  // D6
constexpr int PIN_TFT_SCK = 8;      // D8
constexpr int PIN_TFT_MOSI = 10;    // D10
constexpr int PIN_BATTERY_ADC = 3;  // D1 / A1
constexpr bool HAS_BATTERY_MONITOR = true;

#else
#error "Unsupported target: select ESP32S3 Dev Module or XIAO_ESP32C3/ESP32C3 Dev Module"
#endif

constexpr uint16_t DISPLAY_W = 128;
constexpr uint16_t DISPLAY_H = 128;
constexpr uint32_t TFT_SPI_HZ = 27000000;
constexpr uint8_t ENCODER_STEPS_PER_DETENT = 4;
constexpr uint32_t DEBOUNCE_MS = 30;
constexpr uint32_t MENU_HOLD_MS = 1200;
constexpr uint32_t POWER_OFF_HOLD_MS = 3500;
constexpr uint32_t BUTTON_AFTER_ROTATION_GUARD_MS = 500;
constexpr uint8_t MAX_PHOTOS = 50;

constexpr uint32_t SLIDE_INTERVALS_MS[] = {2000, 3500, 5000, 10000, 30000};
constexpr uint16_t AUTO_SLEEP_MINUTES[] = {0, 1, 3, 5};
constexpr uint8_t OPTION_COUNT = 4;
constexpr uint8_t BRIGHTNESS_LEVELS[] = {64, 128, 191, 255};
constexpr uint8_t BRIGHTNESS_PERCENT[] = {25, 50, 75, 100};
constexpr uint8_t BRIGHTNESS_OPTION_COUNT = 4;
constexpr uint8_t SETTINGS_ITEM_COUNT = 3;
constexpr float BATTERY_DIVIDER_RATIO = 2.0f;
constexpr uint8_t BATTERY_SAMPLE_COUNT = 16;

constexpr char AP_SSID[] = "FilmMemory-Setup";
constexpr char AP_PASSWORD[] = "film2026";

constexpr uint8_t MENU_ITEM_COUNT = 5;
constexpr uint8_t EXPRESSION_COUNT = 10;

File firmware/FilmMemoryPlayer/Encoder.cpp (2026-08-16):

#include "Encoder.h"

#include "AppState.h"
#include "Config.h"
#include "DisplayUtils.h"
#include "EmoteMode.h"
#include "MenuMode.h"
#include "PhotoMode.h"
#include "PowerManager.h"
#include "SettingsMode.h"
#include "WifiManager.h"

void pollEncoder() {
  const uint8_t state = (digitalRead(PIN_ENCODER_A) << 1) | digitalRead(PIN_ENCODER_B);
  if (state != encoderPrevious) {
    lastEncoderActionAt = millis();
    lastUserActionAt = millis();
  }
  const uint8_t transition = (encoderPrevious << 2) | state;
  static const int8_t table[16] = {0, -1, 1, 0, 1, 0, 0, -1, -1, 0, 0, 1, 0, 1, -1, 0};
  encoderAccumulated += table[transition & 0x0F];
  encoderPrevious = state;

  int8_t direction = 0;
  if (encoderAccumulated >= ENCODER_STEPS_PER_DETENT) {
    encoderAccumulated = 0;
    direction = 1;
  } else if (encoderAccumulated <= -ENCODER_STEPS_PER_DETENT) {
    encoderAccumulated = 0;
    direction = -1;
  }
  if (direction == 0) return;

  switch (appMode) {
    case AppMode::PHOTO:
      changePhoto(direction);
      break;
    case AppMode::MENU:
      menuSelection = (menuSelection + MENU_ITEM_COUNT + direction) % MENU_ITEM_COUNT;
      drawMenu();
      break;
    case AppMode::EMOTES:
      changeExpression(direction);
      break;
    case AppMode::SETTINGS:
      if (settingsSelection == 0) {
        slideIntervalIndex = (slideIntervalIndex + OPTION_COUNT + direction) % OPTION_COUNT;
      } else if (settingsSelection == 1) {
        autoSleepIndex = (autoSleepIndex + OPTION_COUNT + direction) % OPTION_COUNT;
      } else {
        brightnessIndex =
            (brightnessIndex + BRIGHTNESS_OPTION_COUNT + direction) % BRIGHTNESS_OPTION_COUNT;
        setBacklight(true);
      }
      saveSettings();
      drawSettings();
      break;
    default:
      break;
  }
}

void pollButton() {
  const bool reading = digitalRead(PIN_ENCODER_SW);
  uint32_t now = millis();
  if (reading != buttonLastReading) buttonChangedAt = now;

  if (now - buttonChangedAt > DEBOUNCE_MS && reading != buttonStable) {
    buttonStable = reading;
    if (buttonStable == LOW) {
      buttonPressedAt = now;
      lastUserActionAt = now;
      menuHoldHandled = false;
      longPressHandled = false;
    } else if (!menuHoldHandled && !longPressHandled) {
      lastUserActionAt = now;
      if (appMode == AppMode::WIFI || setupMode) {
        stopSetupServer();
        appMode = AppMode::MENU;
        scanPhotos();
        drawMenu();
      } else if (appMode == AppMode::MENU) {
        enterSelectedMode();
      } else if (appMode == AppMode::PHOTO) {
        if (now - lastEncoderActionAt >= BUTTON_AFTER_ROTATION_GUARD_MS) {
          autoplay = !autoplay;
          lastSlideAt = millis();
          Serial.printf("Slideshow: %s\n", autoplay ? "ON" : "OFF");
        }
      } else if (appMode == AppMode::SETTINGS) {
        settingsSelection = (settingsSelection + 1) % SETTINGS_ITEM_COUNT;
        drawSettings();
      }
    }
  }

  // 長按 1.2 秒開啟主選單；從任一模式都使用同一個返回手勢。
  if (buttonStable == LOW && !menuHoldHandled &&
      (now - buttonPressedAt >= MENU_HOLD_MS)) {
    menuHoldHandled = true;
    if (appMode != AppMode::MENU) openMainMenu();
  }

  // 繼續按住到 3.5 秒才休眠關機。
  if (buttonStable == LOW && !longPressHandled &&
      (now - buttonPressedAt >= POWER_OFF_HOLD_MS)) {
    longPressHandled = true;
    enterSleep();
  }
  buttonLastReading = reading;
}

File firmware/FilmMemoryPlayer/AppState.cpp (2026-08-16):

#include "AppState.h"

void FilmMemoryST7789::use128x128ZeroOffset() {
  setColRowStart(0, 0);
  setRotation(0);
}

FilmMemoryST7789 tft(&SPI, PIN_TFT_CS, PIN_TFT_DC, PIN_TFT_RST);
WebServer server(80);
Preferences preferences;
uint16_t photoFrame[DISPLAY_W * DISPLAY_H];

const char *const MENU_LABELS[MENU_ITEM_COUNT] = {
    "PHOTO", "CLOCK", "EMOTES", "WI-FI", "SETTINGS"};
AppMode appMode = AppMode::PHOTO;
uint8_t menuSelection = 0;
uint8_t settingsSelection = 0;
uint8_t slideIntervalIndex = 1;
uint8_t autoSleepIndex = 0;
uint8_t brightnessIndex = BRIGHTNESS_OPTION_COUNT - 1;
uint8_t currentExpression = 0;
bool expressionSelectionDirty = false;
uint32_t expressionSelectionChangedAt = 0;

String photos[MAX_PHOTOS];
uint8_t photoCount = 0;
uint8_t currentPhoto = 0;
bool fileSystemReady = false;
bool setupMode = false;
bool webRoutesConfigured = false;
bool autoplay = false;
bool sleeping = false;
uint32_t lastSlideAt = 0;
uint32_t lastEncoderActionAt = 0;
uint32_t lastUserActionAt = 0;
uint32_t lastClockDrawAt = 0;

uint8_t encoderPrevious = 0;
int8_t encoderAccumulated = 0;
bool buttonLastReading = HIGH;
bool buttonStable = HIGH;
uint32_t buttonChangedAt = 0;
uint32_t buttonPressedAt = 0;
bool menuHoldHandled = false;
bool longPressHandled = false;

File uploadFile;
bool uploadOK = false;
String uploadError;

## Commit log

2026-08-10 feat: 完成基本功能與測試
    [partitions.csv]
2026-08-10 feat: 完成外殼模型
    [1.stl, 2.stl, 3.stl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]
2026-08-12 feat: 整合 XIAO ESP32-C3 與 ESP32-S3 Super Mini 版本
    [1.stl, 2.stl, 3.stl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]
2026-08-12 feat: 加入模式選單、時鐘與播放設定
2026-08-12 feat: 改善照片切換流暢度並在時鐘畫面顯示星期
2026-08-13 feat: 更新外殼 STL 模型並整理 3D 列印零件資料夾
    [1.stl, 2.stl, 3.stl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]
2026-08-15 feat: 新增表情頁
2026-08-15 refactor: 將韌體模組化為獨立的元件
2026-08-15 refactor: 統一 ESP32-S3 和 ESP32-C3 的韌體
    [partitions.csv]
2026-08-16 feat: 更新外殼 STL 模型並整理檔案
    [1.stl, 2.stl, 3.stl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]
2026-08-16 feat: 新增調節顯示亮度功能
2026-08-20 feat: 新增電量顯示功能
2026-09-18 feat: 更新外殼 STL 模型
    [1.stl, 2.stl, 3.stl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]
